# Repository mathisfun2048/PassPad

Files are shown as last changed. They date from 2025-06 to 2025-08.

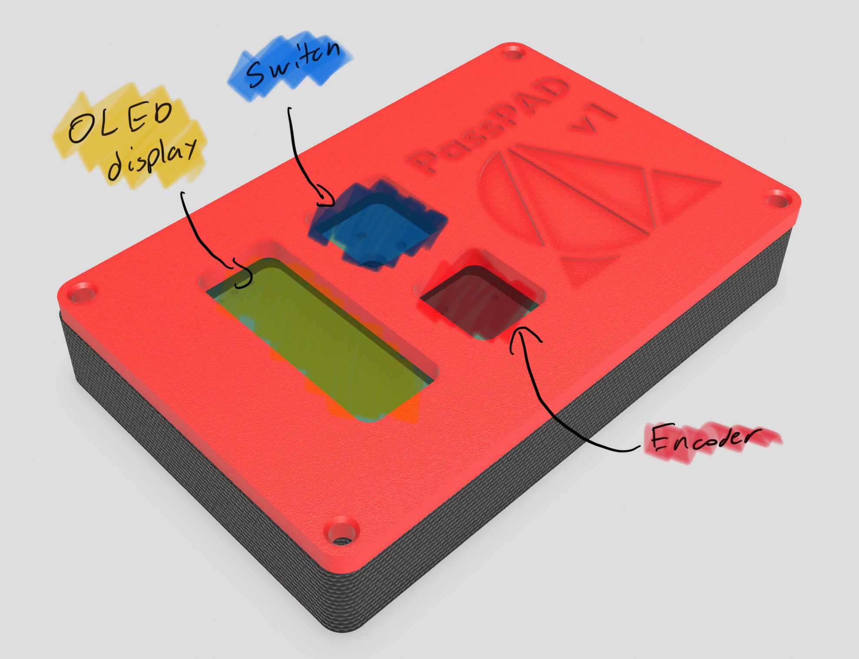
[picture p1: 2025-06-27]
Assests/CAD_Case_Together_Front.jpg

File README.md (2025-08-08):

# PassPAD 

Initial Sketch



## Description and Exigence

This is my fourth attempt at hardware design, and it's been so much fun!

One thing I've been dreading about starting college is moving away from my mac to use a windows laptop for my engineering degree. One of my key contentions was not being able to use the in-built password manger to hold large, secure passwords that I would have otherwise not been able to memorize. This project aims to help me in this problem. 

This device is going to hold passwords with a nickname. The encoder will be able to rotate between saved passwords, with the nickname appearing on the OLED dispaly. The password can be "typed" by repeatedly pressing the switch, which will dynamically change to the charachter next in the password. As a password is being typed, a completion bar will appear on the OLED> After the password is typed, a "completed" message will appear on the oled.

While the hardware for this is pretty simple, the software was not. Instead of being able to use the KMK or QMK frameworks, I learned circuitpython to make this hardware truly custom. I havn't seen a physical password transporter anywhere on the market, so it was really cool building this from scratch. (I submitted it as a 4-point project as my BOM ~$50 , but if you think it may warrent 6 points, please upgrade it :3 )

The design philosophy behind the CAD case for this is similar to my PaperCAM project: I wanted it to be sleek and minimal, in part not to draw attention. This, after all, contains my passwords! I do not want it to be flashy. That's why the case looks quite non-descrcipt. I wanted to add some custimizations, though, so I engraved my logo and a text that reads "PassPad v1". 

In line with keeping things simple (and affordable), I chose a very minimalistic BOM. Here it is below! It is also copied at the end of this README. 

NOTE: I know some items can be found cheaper through other retailars: the only problem is that my parents will only let me buy from the retailors below. If the cost goes above teh allocated cost for my project, I will hapilly pay out of my own pocket. I am grateful to have the opportunity to build this, and I cannot do so if I don't buy the parts from the retailors below.

|Item |Quantity|Cost |Link |
|---|---|-----|---|
|0.91 OLED Display  |1 |5.99 |https://www.amazon.com/gp/product/B08F9F8BYB/ref=ewc_pr_img_3?smid=A3CX4TQNUXMB0L&th=1 |
|EC11 Rotary Encoder|1 |0 |n/a I should have spares from the Hackpad kit |
|MX-Style Switch |1 |0 |n/a I should have spares from the Hackpad kit |
|White DSA Keycap |1 |0 |n/a I should have spares from the Hackpad kit|
                                                                                                                                            |
|XIAO Microprocessor|1       |9.99 |https://www.amazon.com/gp/product/B09NNVNW7M/ref=ox_sc_act_title_1?smid=A1YP59NGBNBZUR&psc=1                                                                                                                                                                                                                                                                                                                                                                                                                                                                 |
|Custom PCB         |1       |2  + shipping  |https://jlcpcb.com                                                                                                                                                                                                                                                                                                                                                                                                                                                                                                                                           |
|2.5M x 4mm Screws  |8       |0    |n/a, self-provided                                                                                                                                                                                                                                                                                                                                                                                                                                                                                                                                           |
|                   |        |~$38|                                                                                                                                                                                                                                                                                                                                                                                                                                                                                                                                                             |

## Schematic and PCB Design

For this project, I kept pretty much exactly to my initial sketch. Here's some images!

### Schematic
Screenshot 2025-07-02 at 4 01 11 AM

### PCB
Screenshot 2025-07-02 at 4 00 47 AM

## Firmware

Custom firmware! It was super fun to make. If you want a detailed view into my mindset, check out my journal! The runtime script is also included in this repo under the firmware and production directories. 

The code for this project was signficantly longer than teh code for my other projects (being ~600ish lines). I think that's a record for me! I experienced a lot of growth as a dev in this project as I was really able to exercise skills in error handeling and encryption. It was really satisfying to know that the code I have is for a project that I will use rather than something for a test. 

## CAD

The CAD case, like I said above, is simple by design: it is meant to be non-descript so people don't want to steal my passwords (litteraly). Here's some pretty renders of how everything looked at the end. Also, like the PaperCAM, as there is no wiring outside the PCB, no pretty sketch :(. However, I did annotate some of teh images below!

CAD_Case_Together_Front
CAD_Case_Together_Back
CAD_Case_Seperated_Front

## BOM

NOTE: I know some items can be found cheaper through other retailars: the only problem is that my parents will only let me buy from the retailors below. If the cost goes above teh allocated cost for my project, I will hapilly pay out of my own pocket. I am grateful to have the opportunity to build this, and I cannot do so if I don't buy the parts from the retailors below.

|Item |Quantity|Cost |Link |
|---|---|-----|---|
|0.91 OLED Display  |1 |5.99 |https://www.amazon.com/gp/product/B08F9F8BYB/ref=ewc_pr_img_3?smid=A3CX4TQNUXMB0L&th=1 |
|EC11 Rotary Encoder|1 |0 |n/a I should have spares from the Hackpad kit |
|MX-Style Switch |1 |0 |n/a I should have spares from the Hackpad kit |
|White DSA Keycap |1 |0 |n/a I should have spares from the Hackpad kit|
                                                                                                                                                                                                                                                                                                                                           |
|XIAO Microprocessor|1       |9.99 |https://www.amazon.com/gp/product/B09NNVNW7M/ref=ox_sc_act_title_1?smid=A1YP59NGBNBZUR&psc=1                                                                                                                                                                                                                                                                                                                                                                                                                                                                 |
|Custom PCB         |1       |2  + shipping  |https://jlcpcb.com                                                                                                                                                                                                                                                                                                                                                                                                                                                                                                                                           |
|2.5M x 4mm Screws  |8       |0    |n/a, self-provided                                                                                                                                                                                                                                                                                                                                                                                                                                                                                                                                           |
|                   |        |~$38|                                                                                                                                                                                                                                                                                                                                                                                                                                                                                                                                                             |

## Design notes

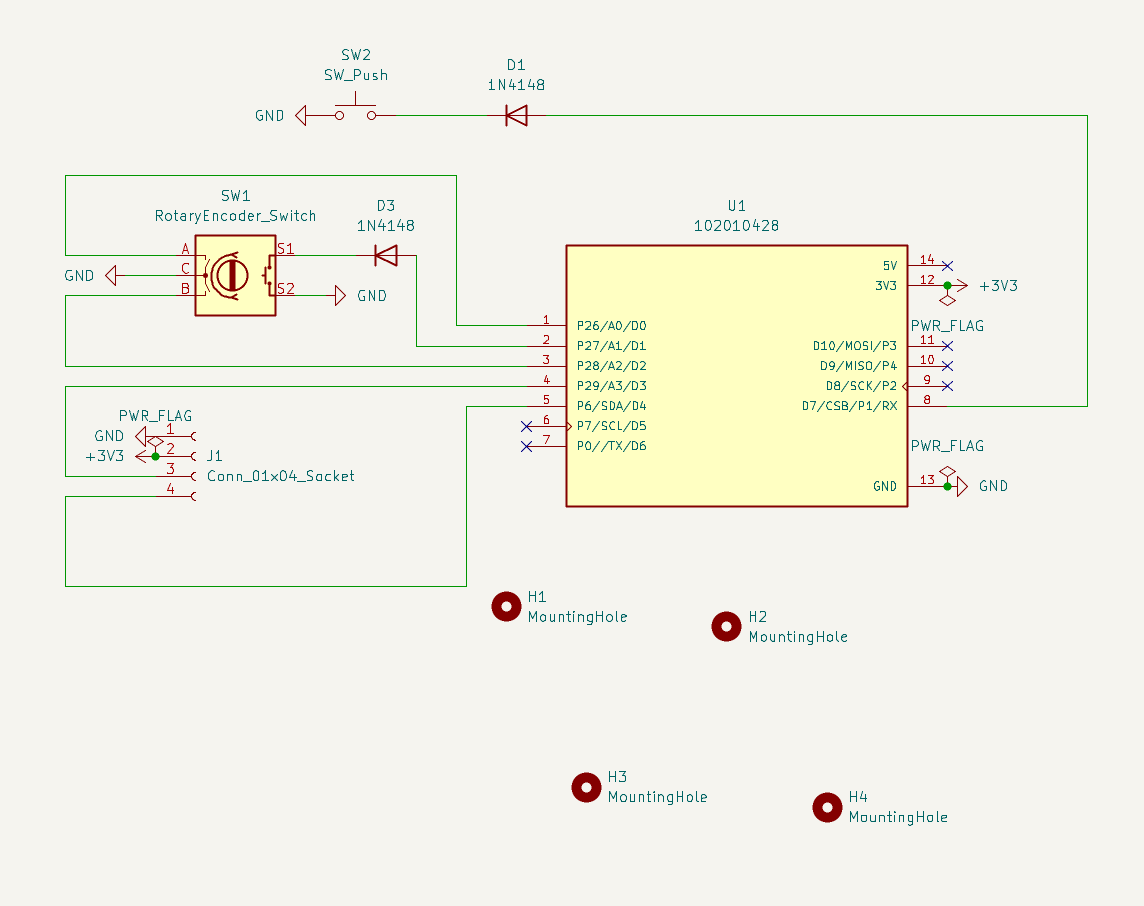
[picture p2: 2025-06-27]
Assests/Schematic.png

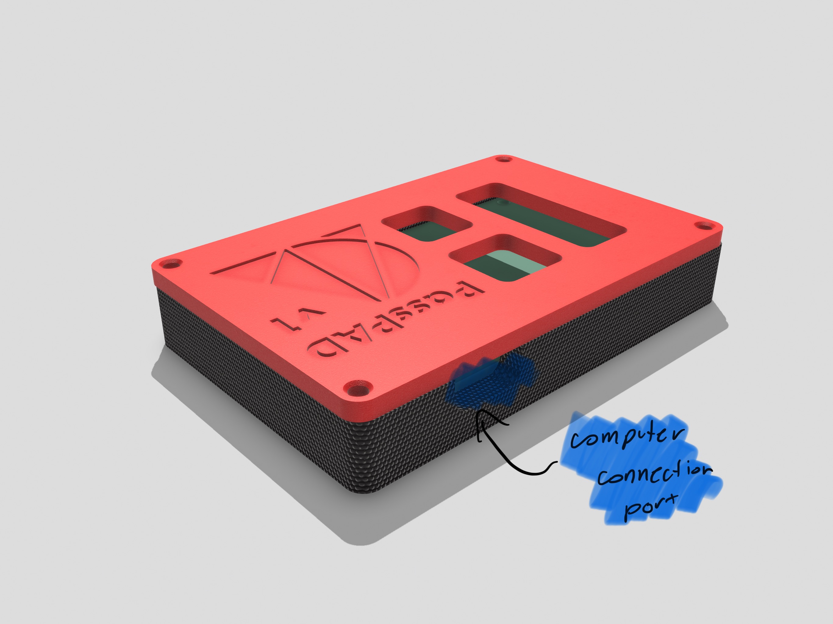
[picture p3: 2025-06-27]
Assests/CAD_Case_Together_Back.jpg

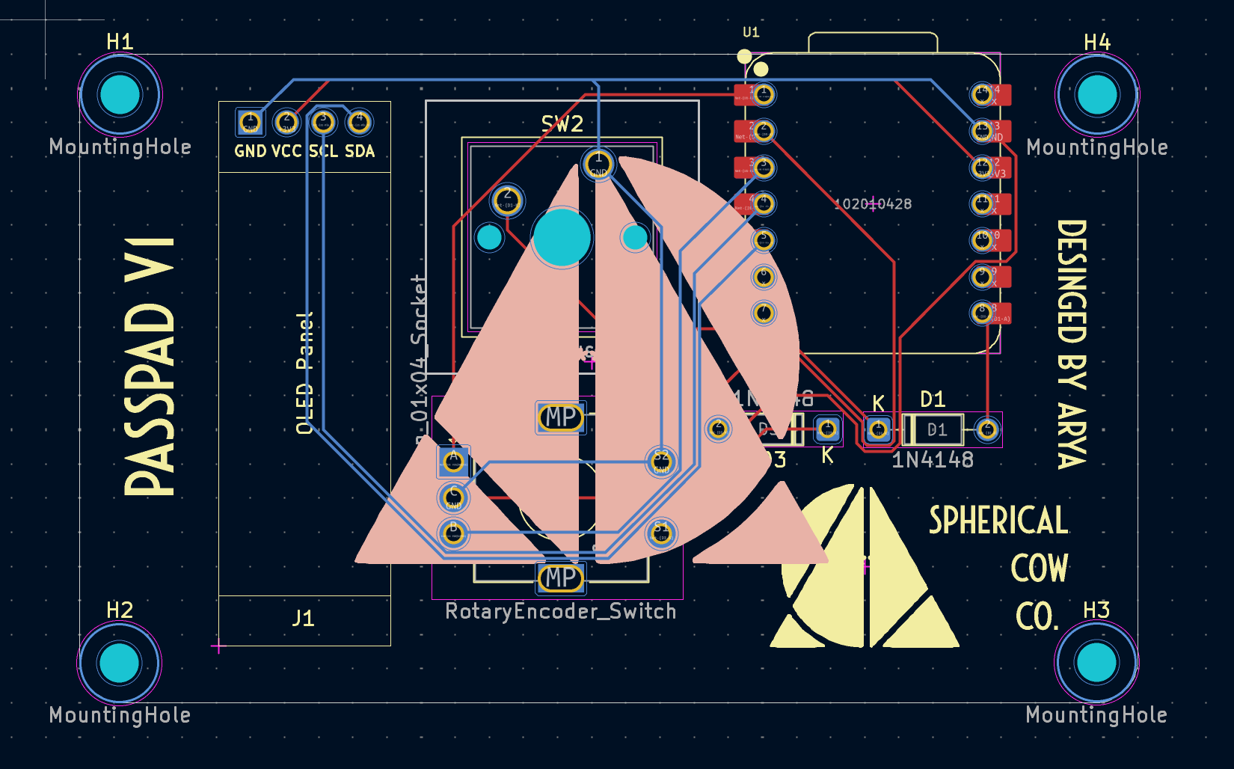
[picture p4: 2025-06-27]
Assests/PCB.png

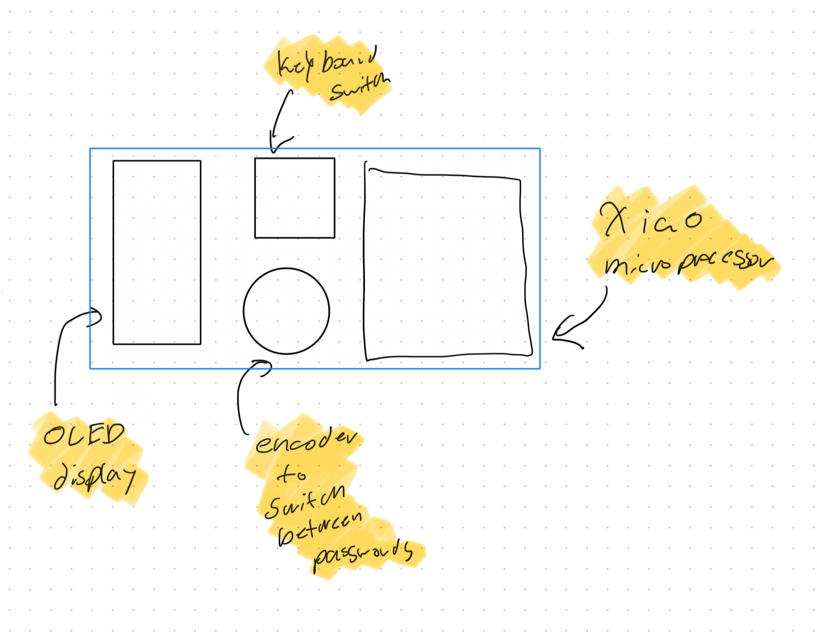
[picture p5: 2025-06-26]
Assests/Initial Sketch.jpg

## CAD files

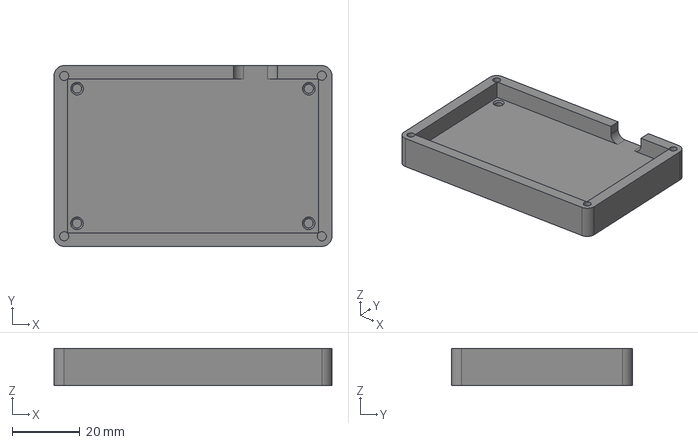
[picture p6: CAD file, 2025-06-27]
CAD/PassPAD_Case_Separates_STEP/Body 133.step
81.8 x 53.2 x 11.0 mm

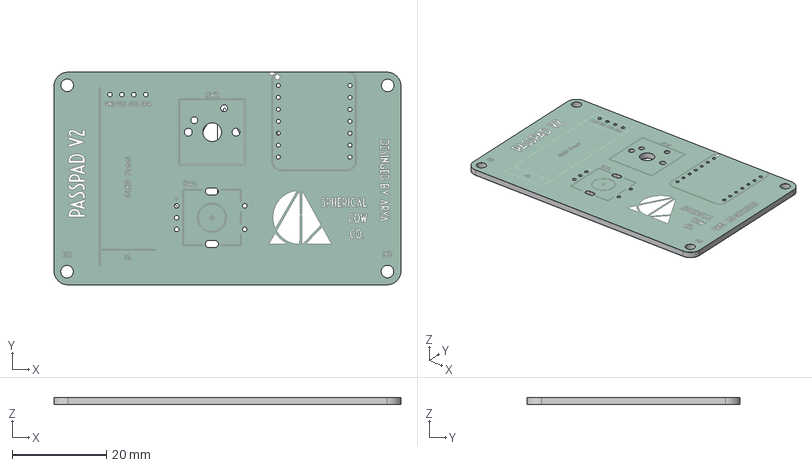
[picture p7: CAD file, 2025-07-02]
CAD/PassPad_PCB_STEP.step
73.8 x 45.2 x 1.66 mm
PassPad_KiCAD_silkscreen
PassPad_KiCAD_soldermask
PassPad_KiCAD_PCB

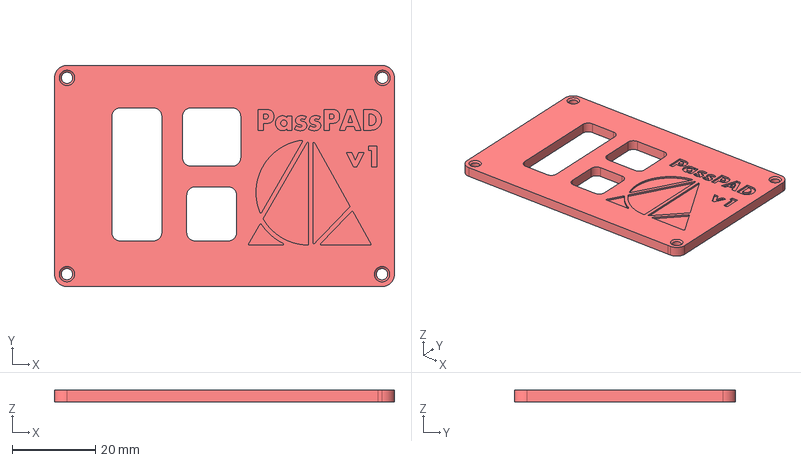
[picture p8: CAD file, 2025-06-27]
CAD/PassPAD_Case_Separates_STEP/Body 140.step
81.8 x 53.2 x 3.00 mm

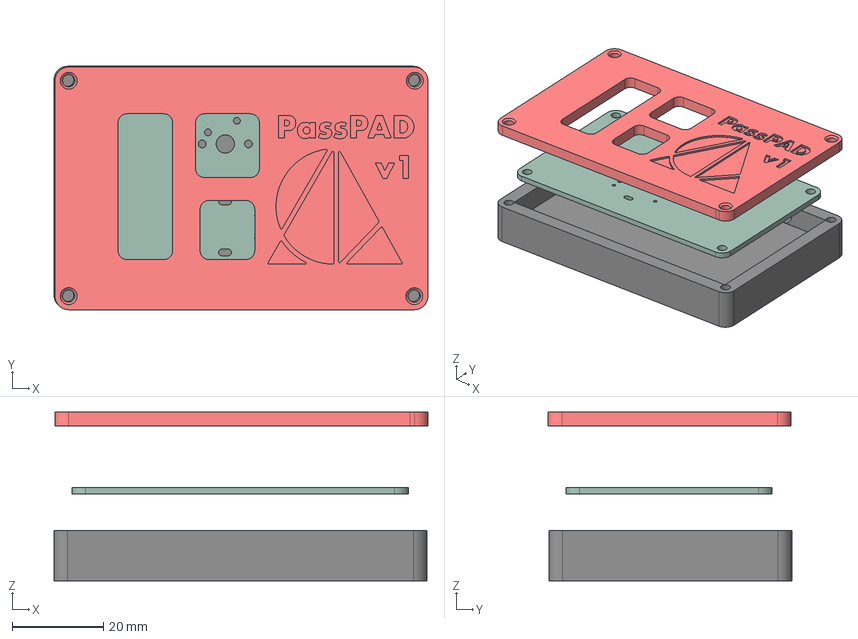
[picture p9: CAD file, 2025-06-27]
CAD/PassPAD_Together.step
82.0 x 53.4 x 37.0 mm
final logo doc svg
PassPad_KiCAD_PCB

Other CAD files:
Production/PassPAD_STL_Seperates/Body 133.stl
Production/PassPAD_STL_Seperates/Body 140.stl

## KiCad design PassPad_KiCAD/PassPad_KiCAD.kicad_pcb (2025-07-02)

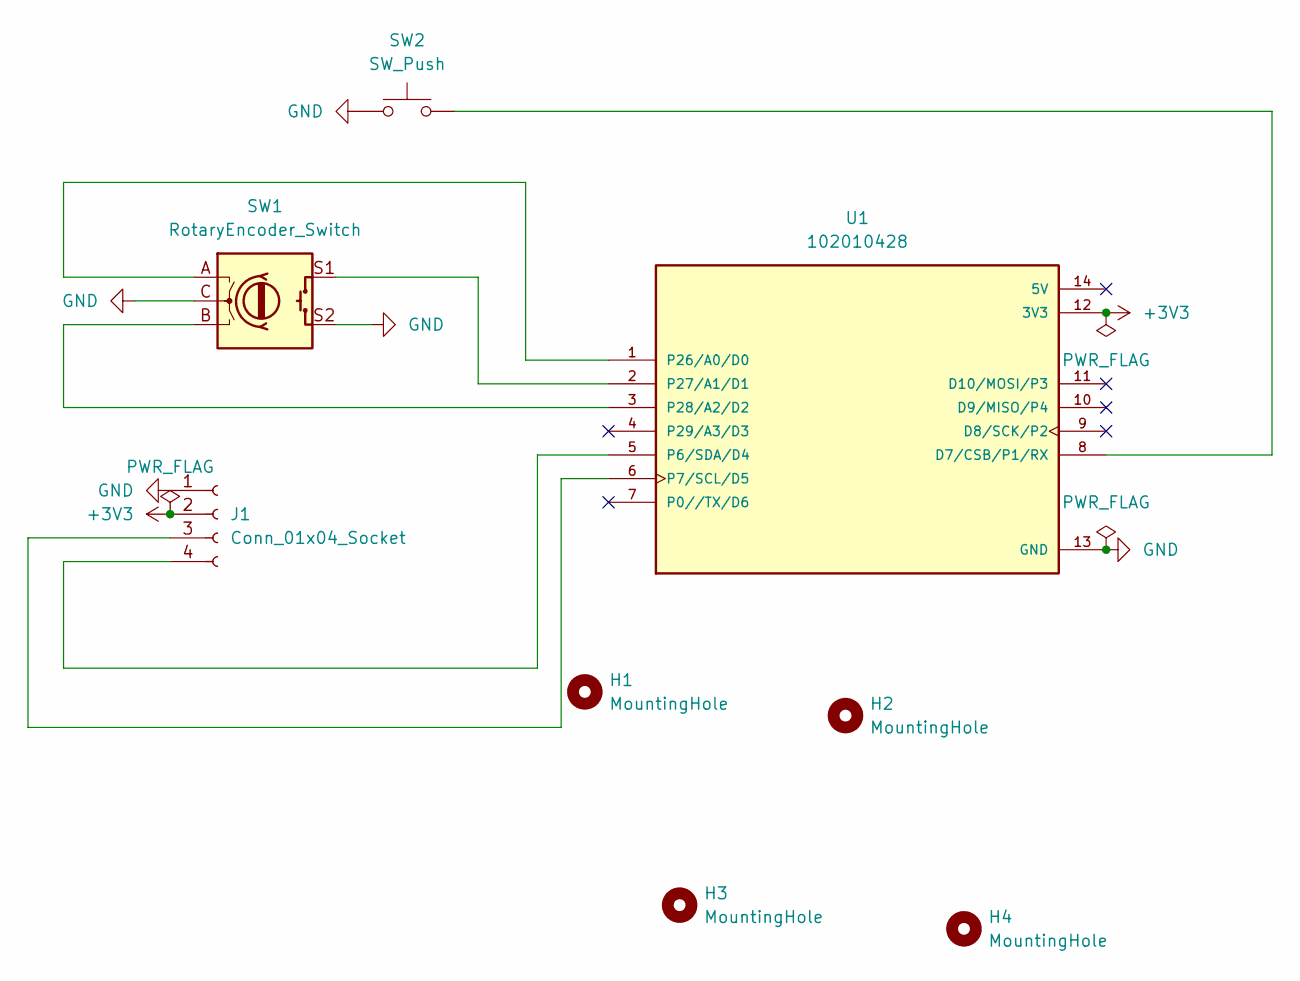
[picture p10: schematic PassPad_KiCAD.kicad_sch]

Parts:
H1, H2, H3, H4: MountingHole; MountingHole_2.7mm_M2.5
J1: Conn_01x04_Socket; SSD1306-0.91-OLED-4pin-128x32
SW1: RotaryEncoder_Switch; RotaryEncoder_Alps_EC11E-Switch_Vertical_H20mm
SW2: SW_Push; SW_Cherry_MX_1.00u_PCB
U1: 102010428; XIAO-through-hole; PARTREV 1.3; DigiKey_Part_Number 1597-102010428-ND

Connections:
+3V3: J1.2, U1.12 (3V3)
GND: J1.1, SW1.C, SW1.S2, SW2.1, U1.13 (GND)
unnamed: J1.3, U1.6 (P7/SCL/D5)
unnamed: J1.4, U1.5 (P6/SDA/D4)
unnamed: SW2.2, U1.8 (D7/CSB/P1/RX)
unnamed: SW1.A, U1.1 (P26/A0/D0)
unnamed: SW1.S1, U1.2 (P27/A1/D1)
unnamed: SW1.B, U1.3 (P28/A2/D2)

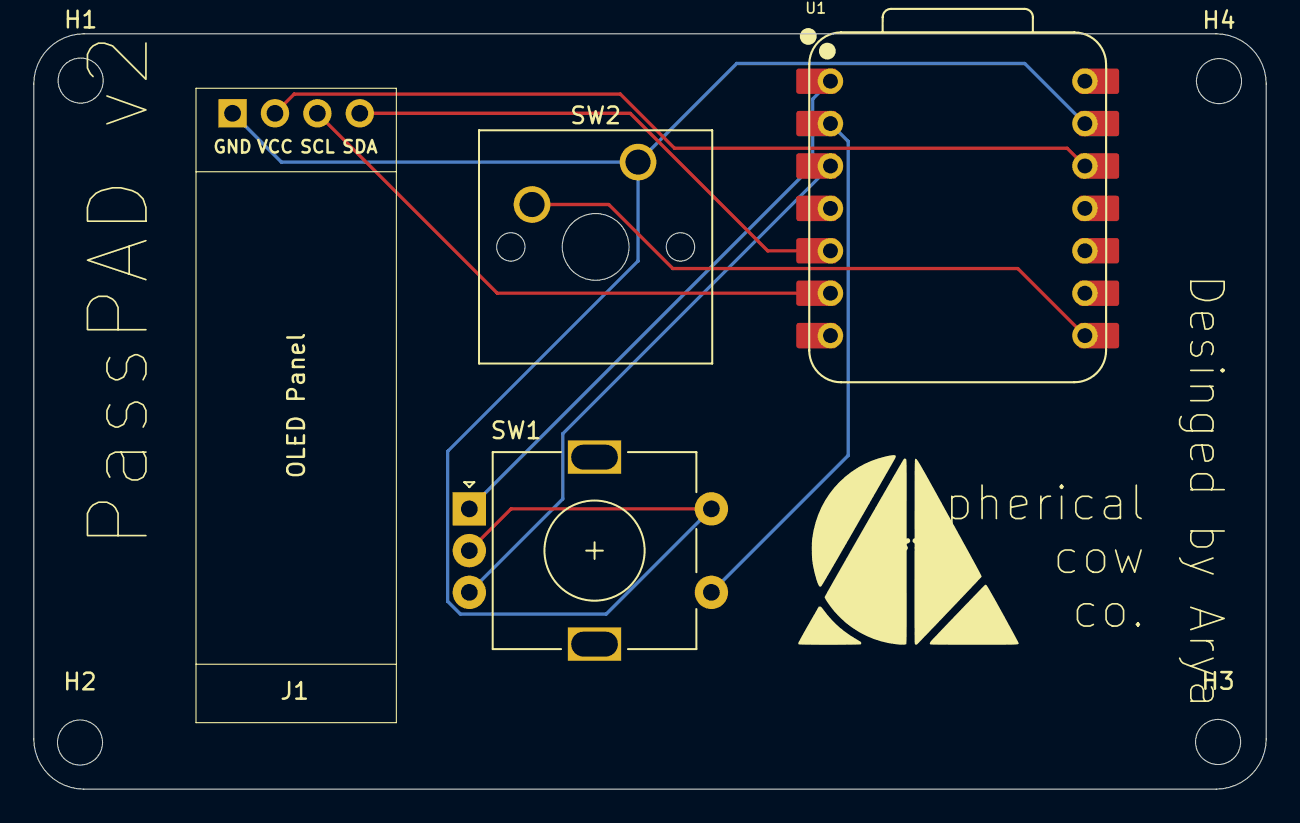
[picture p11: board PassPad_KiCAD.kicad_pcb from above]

Board: 2 copper layers, 73.8 x 45.2 mm, 8 parts (0 on the bottom side), 8 nets.

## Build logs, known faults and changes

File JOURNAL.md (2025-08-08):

---
title: "PassPad"
author: "Arya C."
description: "Convinent way to physically transport a password! (I love my password manager but what if I need to log into a public device where I don't want to link that?)"
created_at: "06-26-2025"
---

time spent (so far): 22 hours

# June 26

## 2PM -> 3PM (1 hour)

Spent this time researching possible parts and drawing a sketch of what I want this to look like. After, I wrote out the explicit objectives of this project. 

### Initial Sketch
Initial Sketch

### Interem BOM
- 0.91 OLED Display
- EC11 Rotary Encoder
- MX-Style Switch
- White DSA Keycap
- 1N4148 Diodes
- XIAO Microprocessor
- Custom PCB
- 3D Printed Case
- 2.5M x 4mm Screws

### Required Functionality
This project is meant to be a compact password transporter to where you need to have a secure password but don't want to log into your password manager. 

- This device should be able to store multiple passwords which the encoder should be able to rotate between
- The OLED pannel should display a short codename for the password (e.x. "password 1")
- The switch should then be repeatedly pressed until the password in its entierity is transmitted
- After the password is transmitted, no new data should be pushed even if the switch is pressed. The OLED pannel should communicate that the password has been transmitted (e.x. "successful")

sidenote: i've been going into a slump over desiging and itterating complex designs so I thought making this would be a fun in-between project. 

## 6PM -> 8PM (2 hours)

While making the schematic, went into a deep-dive on how microprocessors work! In the past, I only really worked with full on machines (raspberri pi zeros, 3b+) so seeing how this worked in a custom project was pretty cool. 

After looking into that, I started on my PCB schematic. This is, compared to my other projects, stupidly simple. But it was cool nonetheless--I have never seen a similar device in the wild and it feels really cool being able to build something. 

Schematic

### GPIO Guide
- 3.3v -> 3.3V (-> implicitly attached to VCC on display)
- GND -> GND (-> implicitly attached to GND on display, C pin on encoder, switch on encoder, and switch)
- Pin 1 -> diode -> one side of switch (other side is grounded)
- Pin 26 -> A pin on encoder
- Pin 27 -> diode -> one side of switch on encoder (other switch on encoder is grounded)
- Pin 28 -> B pin on encoder
- Pin 29 -> SCL on display
- Pin 6 -> SDA on display

now onto the PCB design!

## 8PM -> 9PM (1 hour)

Finished the PCB!

Screenshot 2025-06-27 at 2 07 22 AM

Now time for the beast: coding it. I remember last time I used micropython with this controler and it wasn't the worst... lets see how this goes. This project, in my opinion, is more complex algorithmically than the hackpad (which has a lot of open keyboard examples online which I could directly learn from). This is me operating it all on my own! I hope it'll be fun though...

# June 27

## 9PM -> 5AM 7AM -> 2PM (15 hours)

Finished my code! 

Who could have thought this would be so complicated! 

Okay so here was my process:
At first I started with micropython, becasue I thought it would be a similar proccess as to my hackpad. I was wrong....

Because my device is not purely a keybaord, I could not use KMK libraries... fun fun

So I went searching for soemthing that would be a tad bit more usable per my skill level, and I discovered circuit python! Which had a LOT of libraries I could use to not work in low-level code! YAY!

Here is everything I was able to import to help with the code:

Screenshot 2025-06-27 at 1 36 20 PM

One thing that I saw that made my code more rohbust was me being able to incorporate error handeling! I first truly learned the neccesity of it while making my PaperCAM project, and it was nice being able to see my learning and apply it to this. Error handeling is present primarily if the host device does not support HID, in which case the OLED pannel will display an error message. 

I wanted to incorporate a "copy" mode but then was lazy and forgot to do it. However, I was able to implement OS detection, so it will be reletivily easy to implmement that in the future. The reason I need OS detection is because I use a Mac which does not interpret CTRL+C as CMD+C. 

Overall, this was pretty fun, and you can see the full code in main.py under the firmware folder. 

I don't know really what else to add here, because my code is just a representation of my desgin statements that I made earlier in this journal. 

Now, onto the CAD!

## 2PM -> 4PM (2 Hours)

Finished the CAD case!

CAD_Case_Together_Front
CAD_Case_Together_Back
CAD_Case_Seperated_Front

## 4PM -> 5PM (1 Hour)

Put the repo all together for submission!

# July 2 

## 2AM -> 4AM (2 hours)

Was about to send this to print, but found some things I could revise. First, the dispaly wasn't wired propelry. I also found out that the display on my hackpad wasn't wired properly! I will have to change teh I2C on that manually through software. For this, though, I was able to fix it. I also removed teh diodes as they had no real purpous. I also cleaned up the PCB wiring. 

Screenshot 2025-07-02 at 3 58 58 AM

Screenshot 2025-07-02 at 3 59 11 AM

# I belive I have everything prepped for this project, including a Custom PCB, Custom Firmware, Custom Case, and associated components. The next step for me is to order my components and build this thing! Very excited

# One quick (and big) thank you to hack club for motivating me to do this project. Its ben an amazing run--thank you!

# August 4th 6PM -> 10PM (4 hours)

finally got around to making this!



was fairly easy, because I was able to re-use a lot of elements from my macropad. the soldering also went by well... im glad I'm getting better! I don't knwo what else to add here, because everything went smoothly, including the software, which is surprising. 

here is a demo video: https://youtube.com/shorts/AUEiD2HvVok

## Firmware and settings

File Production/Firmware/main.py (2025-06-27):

import time
import board
import busio
import digitalio
import rotaryio
import displayio
import terminalio
from adafruit_display_text import label
import adafruit_displayio_ssd1306
import usb_hid
from adafruit_hid.keyboard import Keyboard
from adafruit_hid.keycode import Keycode
import supervisor
import gc

CONFIG = {
    "os_type": "windows",
    "typing_delay": 0.02,
    "auto_lock_timeout": 300,
    "screen_brightness": 1.0,
}

DEVICE_KEY = 0xA5

def obfuscate_password(password):
    return ''.join(chr(ord(c) ^ DEVICE_KEY) for c in password)

def deobfuscate_password(obfuscated):
    return ''.join(chr(ord(c) ^ DEVICE_KEY) for c in obfuscated)

PASSWORDS = [
    {"name": "Password_1", "password": obfuscate_password("1234!")},
    {"name": "Password_2", "password": obfuscate_password("password")},
    {"name": "Password_3", "password": obfuscate_password("very-secure")},
    {"name": "Password_4", "password": obfuscate_password("passwordpassword")},
    {"name": "Password_5", "password": obfuscate_password("drowssap")},
]

class PasswordManagerError(Exception):
    pass

class PasswordManager:
    def __init__(self):
        self.error_count = 0
        self.max_errors = 5
        self.error_state = False
        self.last_error = None
        self.config_mode = False
        self.locked = False
        self.last_activity = time.monotonic()

        try:
            self.initialize_system()
        except Exception as e:
            self.handle_critical_error(f"Initialization failed: {e}")
            raise

    def initialize_system(self):
        print("Initializing Password Manager...")

        self.initialize_display()

        self.setup_hardware()

        self.initialize_hid()

        self.initialize_state()

        self.update_display()
        print("Password Manager initialization complete")

    def initialize_display(self):
        max_retries = 3
        for attempt in range(max_retries):
            try:
                displayio.release_displays()
                time.sleep(0.1)

                i2c = busio.I2C(board.P29, board.P6)
                display_bus = displayio.I2CDisplay(i2c, device_address=0x3C)
                self.display = adafruit_displayio_ssd1306.SSD1306(display_bus, width=128, height=32)

                self.splash = displayio.Group()
                self.display.show(self.splash)
                return

            except Exception as e:
                print(f"Display init attempt {attempt+1} failed: {e}")
                if attempt == max_retries - 1:
                    raise PasswordManagerError(f"Display initialization failed after {max_retries} attempts")
                time.sleep(0.5)

    def setup_hardware(self):
        try:
            self.switch = digitalio.DigitalInOut(board.P1)
            self.switch.direction = digitalio.Direction.INPUT
            self.switch.pull = digitalio.Pull.DOWN

            try:
                self.encoder = rotaryio.IncrementalEncoder(board.P26, board.P28)
                self.encoder_available = True
            except Exception as e:
                print(f"Encoder initialization failed: {e}")
                self.encoder = None
                self.encoder_available = False

            self.encoder_switch = digitalio.DigitalInOut(board.P27)
            self.encoder_switch.direction = digitalio.Direction.INPUT
            self.encoder_switch.pull = digitalio.Pull.DOWN

        except Exception as e:
            raise PasswordManagerError(f"Hardware setup failed: {e}")

    def initialize_hid(self):
        self.keyboard = None
        self.hid_available = False

        try:
            if not usb_hid.devices:
                print("Warning: No USB HID devices found")
                return

            self.keyboard = Keyboard(usb_hid.devices)
            self.hid_available = True

        except Exception as e:
            print(f"USB HID initialization failed: {e}")
            self.keyboard = None
            self.hid_available = False

    def initialize_state(self):
        self.current_password_index = 0
        self.current_char_index = 0
        self.password_transmitted = False
        self.last_encoder_position = self.encoder.position if self.encoder_available else 0

        self.config_option = 0
        self.config_options = ["OS Type", "Typing Delay", "Auto Lock"]

        self.last_switch_time = 0
        self.debounce_delay = 0.3

    def update_activity(self):
        self.last_activity = time.monotonic()

    def check_auto_lock(self):
        if CONFIG["auto_lock_timeout"] > 0 and not self.locked:
            if time.monotonic() - self.last_activity > CONFIG["auto_lock_timeout"]:
                self.locked = True
                self.safe_display_update(self.update_display)

    def unlock_device(self):
        self.locked = False
        self.update_activity()
        self.safe_display_update(self.update_display)

    def secure_clear_password(self, password_data):
        try:
            if isinstance(password_data, str):
                password_data = "0" * len(password_data)
            gc.collect()
        except:
            pass

    def handle_error(self, error_msg):
        self.error_count += 1
        self.last_error = error_msg
        print(f"Error {self.error_count}: {error_msg}")

        if self.error_count >= self.max_errors:
            self.error_state = True
            self.show_error_screen("Too many errors", "Device in safe mode")
            return False

        if "display" in error_msg.lower():
            self.recover_display()
        elif "hid" in error_msg.lower():
            self.recover_hid()
        elif "encoder" in error_msg.lower():
            self.recover_encoder()

        return True

    def handle_critical_error(self, error_msg):
        print(f"CRITICAL ERROR: {error_msg}")
        try:
            if self.display:
                self.show_error_screen("CRITICAL ERROR", "Restarting...")
                time.sleep(3)
        except:
            pass
        supervisor.reload()

    def recover_display(self):
        try:
            self.initialize_display()
            self.update_display()
            return True
        except Exception as e:
            print(f"Display recovery failed: {e}")
            return False

    def recover_hid(self):
        try:
            time.sleep(1)
            self.initialize_hid()
            return self.hid_available
        except Exception as e:
            print(f"HID recovery failed: {e}")
            return False

    def recover_encoder(self):
        try:
            self.encoder = rotaryio.IncrementalEncoder(board.P26, board.P28)
            self.encoder_available = True
            self.last_encoder_position = self.encoder.position
            return True
        except Exception as e:
            print(f"Encoder recovery failed: {e}")
            self.encoder_available = False
            return False

    def show_error_screen(self, title, message):
        try:
            if not self.display:
                return

            self.display.show(None)
            group = displayio.Group()

            text1 = label.Label(terminalio.FONT, text=title, color=0xFFFFFF, x=5, y=8)
            text2 = label.Label(terminalio.FONT, text=message, color=0xFFFFFF, x=5, y=18)
            text3 = label.Label(terminalio.FONT, text="Press encoder to retry", color=0xFFFFFF, x=2, y=28)

            group.append(text1)
            group.append(text2)
            group.append(text3)

            self.display.show(group)
        except Exception as e:
            print(f"Error displaying error screen: {e}")

    def safe_display_update(self, update_func):
        try:
            update_func()
        except Exception as e:
            if not self.handle_error(f"Display update failed: {e}"):
                return False
        return True

    def update_display(self):
        try:
            if self.display:
                self.display.show(None)

            gc.collect()
            self.splash = displayio.Group()

            if self.locked:
                text1 = label.Label(terminalio.FONT, text="DEVICE LOCKED", color=0xFFFFFF, x=15, y=8)
                text2 = label.Label(terminalio.FONT, text="Press encoder", color=0xFFFFFF, x=18, y=18)
                text3 = label.Label(terminalio.FONT, text="to unlock", color=0xFFFFFF, x=25, y=28)
                self.splash.append(text1)
                self.splash.append(text2)
                self.splash.append(text3)

            elif self.config_mode:
                self.display_config_screen()

            elif self.error_state:
                text1 = label.Label(terminalio.FONT, text="SAFE MODE", color=0xFFFFFF, x=25, y=8)
                text2 = label.Label(terminalio.FONT, text="Multiple errors", color=0xFFFFFF, x=8, y=18)
                text3 = label.Label(terminalio.FONT, text="Hold encoder: reset", color=0xFFFFFF, x=2, y=28)
                self.splash.append(text1)
                self.splash.append(text2)
                self.splash.append(text3)

            elif not self.hid_available:
                text1 = label.Label(terminalio.FONT, text="USB HID ERROR", color=0xFFFFFF, x=15, y=8)
                text2 = label.Label(terminalio.FONT, text="Check USB connection", color=0xFFFFFF, x=5, y=18)
                self.splash.append(text1)
                self.splash.append(text2)

            elif self.password_transmitted:
                text1 = label.Label(terminalio.FONT, text="SUCCESS!", color=0xFFFFFF, x=30, y=8)
                text2 = label.Label(terminalio.FONT, text="Password sent", color=0xFFFFFF, x=15, y=18)
                text3 = label.Label(terminalio.FONT, text="Press encoder: reset", color=0xFFFFFF, x=2, y=28)
                self.splash.append(text1)
                self.splash.append(text2)
                self.splash.append(text3)
            else:
                password_info = PASSWORDS[self.current_password_index]

                name = password_info["name"]
                if len(name) > 18:
                    name = name[:15] + "..."
                text1 = label.Label(terminalio.FONT, text=name, color=0xFFFFFF, x=5, y=8)

                actual_password = deobfuscate_password(password_info["password"])

                progress = f"{self.current_char_index}/{len(actual_password)}"
                os_status = f"OS: {CONFIG['os_type']}"
                text2 = label.Label(terminalio.FONT, text=f"{progress}  {os_status}", color=0xFFFFFF, x=5, y=18)

                text3 = label.Label(terminalio.FONT, text="Switch+Enc: config", color=0xFFFFFF, x=5, y=28)

                self.splash.append(text1)
                self.splash.append(text2)
                self.splash.append(text3)

                self.secure_clear_password(actual_password)

            if self.display:
                self.display.show(self.splash)

        except Exception as e:
            print(f"Display update error: {e}")
            self.handle_error(f"Display update failed: {e}")

    def display_config_screen(self):
        global value, value
        option_name = self.config_options[self.config_option]

        if self.config_option == 0:
            value = CONFIG["os_type"]
        elif self.config_option == 1:
            value = f"{CONFIG['typing_delay']:.3f}s"
        elif self.config_option == 2:
            value = f"{CONFIG['auto_lock_timeout']}s" if CONFIG['auto_lock_timeout'] > 0 else "OFF"

        text1 = label.Label(terminalio.FONT, text="CONFIG MODE", color=0xFFFFFF, x=20, y=8)
        text2 = label.Label(terminalio.FONT, text=f"{option_name}: {value}", color=0xFFFFFF, x=5, y=18)
        text3 = label.Label(terminalio.FONT, text="Rotate: change, Press: next", color=0xFFFFFF, x=2, y=28)

        self.splash.append(text1)
        self.splash.append(text2)
        self.splash.append(text3)

    def handle_encoder(self):
        if self.locked or self.error_state or not self.encoder_available:
            return

        try:
            current_position = self.encoder.position
            if current_position != self.last_encoder_position:
                difference = current_position - self.last_encoder_position
                self.update_activity()

                if self.config_mode:
                    self.handle_config_rotation(difference)
                else:
                    if difference > 0:
                        self.current_password_index = (self.current_password_index + 1) % len(PASSWORDS)
                    else:
                        self.current_password_index = (self.current_password_index - 1) % len(PASSWORDS)

                    self.reset_transmission()

                self.last_encoder_position = current_position
                self.safe_display_update(self.update_display)
                time.sleep(0.1)

        except Exception as e:
            print(f"Encoder handling error: {e}")
            if not self.handle_error(f"Encoder error: {e}"):
                self.encoder_available = False

    def handle_config_rotation(self, difference):
        if self.config_option == 0:
            os_types = ["windows", "macos", "linux"]
            current_index = os_types.index(CONFIG["os_type"])
            if difference > 0:
                current_index = (current_index + 1) % len(os_types)
            else:
                current_index = (current_index - 1) % len(os_types)
            CONFIG["os_type"] = os_types[current_index]

        elif self.config_option == 1:
            if difference > 0:
                CONFIG["typing_delay"] = min(0.2, CONFIG["typing_delay"] + 0.01)
            else:
                CONFIG["typing_delay"] = max(0.0, CONFIG["typing_delay"] - 0.01)

        elif self.config_option == 2:
            if difference > 0:
                if CONFIG["auto_lock_timeout"] == 0:
                    CONFIG["auto_lock_timeout"] = 60
                else:
                    CONFIG["auto_lock_timeout"] = min(1800, CONFIG["auto_lock_timeout"] + 60)
            else:
                if CONFIG["auto_lock_timeout"] <= 60:
                    CONFIG["auto_lock_timeout"] = 0
                else:
                    CONFIG["auto_lock_timeout"] = max(0, CONFIG["auto_lock_timeout"] - 60)

    def get_key_mapping(self):
        mapping = {
            '!': (Keycode.SHIFT, Keycode.ONE),
            '@': (Keycode.SHIFT, Keycode.TWO),
            '#': (Keycode.SHIFT, Keycode.THREE),
            '$': (Keycode.SHIFT, Keycode.FOUR),
            '%': (Keycode.SHIFT, Keycode.FIVE),
            '^': (Keycode.SHIFT, Keycode.SIX),
            '&': (Keycode.SHIFT, Keycode.SEVEN),
            '*': (Keycode.SHIFT, Keycode.EIGHT),
            '(': (Keycode.SHIFT, Keycode.NINE),
            ')': (Keycode.SHIFT, Keycode.ZERO),
            '_': (Keycode.SHIFT, Keycode.MINUS),
            '+': (Keycode.SHIFT, Keycode.EQUALS),
            ':': (Keycode.SHIFT, Keycode.SEMICOLON),
            '"': (Keycode.SHIFT, Keycode.QUOTE),
            '<': (Keycode.SHIFT, Keycode.COMMA),
            '>': (Keycode.SHIFT, Keycode.PERIOD),
            '?': (Keycode.SHIFT, Keycode.FORWARD_SLASH),
            '-': (Keycode.MINUS,),
            '=': (Keycode.EQUALS,),
            ';': (Keycode.SEMICOLON,),
            "'": (Keycode.QUOTE,),
            ',': (Keycode.COMMA,),
            '.': (Keycode.PERIOD,),
            '/': (Keycode.FORWARD_SLASH,),
            ' ': (Keycode.SPACE,),
        }

        if CONFIG["os_type"] == "macos":
            mapping['['] = (Keycode.LEFT_BRACKET,)
            mapping[']'] = (Keycode.RIGHT_BRACKET,)
            mapping['\\'] = (Keycode.BACKSLASH,)
            mapping['~'] = (Keycode.SHIFT, Keycode.GRAVE_ACCENT)
            mapping['`'] = (Keycode.GRAVE_ACCENT,)
        else:
            mapping['['] = (Keycode.LEFT_BRACKET,)
            mapping[']'] = (Keycode.RIGHT_BRACKET,)
            mapping['\\'] = (Keycode.BACKSLASH,)
            mapping['~'] = (Keycode.SHIFT, Keycode.GRAVE_ACCENT)
            mapping['`'] = (Keycode.GRAVE_ACCENT,)

        return mapping

    def send_next_character(self):
        if not self.hid_available or self.error_state or self.locked:
            return

        obfuscated_password = PASSWORDS[self.current_password_index]["password"]
        password = deobfuscate_password(obfuscated_password)

        if self.current_char_index >= len(password):
            self.secure_clear_password(password)
            return

        char = password[self.current_char_index]
        key_mapping = self.get_key_mapping()

        try:
            if char in key_mapping:
                self.keyboard.send(*key_mapping[char])
            elif char.isalpha():
                if char.isupper():
                    self.keyboard.send(Keycode.SHIFT, getattr(Keycode, char))
                else:
                    self.keyboard.send(getattr(Keycode, char.upper()))
            elif char.isdigit():
                digit_map = {
                    '0': Keycode.ZERO, '1': Keycode.ONE, '2': Keycode.TWO,
                    '3': Keycode.THREE, '4': Keycode.FOUR, '5': Keycode.FIVE,
                    '6': Keycode.SIX, '7': Keycode.SEVEN, '8': Keycode.EIGHT,
                    '9': Keycode.NINE
                }
                self.keyboard.send(digit_map[char])
            else:
                print(f"Unhandled character: {char}")

            self.current_char_index += 1

            if CONFIG["typing_delay"] > 0:
                time.sleep(CONFIG["typing_delay"])

            if self.current_char_index >= len(password):
                self.password_transmitted = True

            self.secure_clear_password(password)

        except Exception as e:
            self.secure_clear_password(password)
            self.handle_error(f"Failed to send character: {e}")

    def reset_transmission(self):
        self.current_char_index = 0
        self.password_transmitted = False

    def factory_reset(self):
        try:
            self.error_state = False
            self.error_count = 0
            self.last_error = None
            self.config_mode = False
            self.locked = False
            self.reset_transmission()
            self.update_activity()

            CONFIG["os_type"] = "windows"
            CONFIG["typing_delay"] = 0.02
            CONFIG["auto_lock_timeout"] = 300

            self.initialize_hid()
            if not self.encoder_available:
                self.recover_encoder()

            self.safe_display_update(self.update_display)

        except Exception as e:
            self.handle_critical_error("Factory reset failed")

    def run(self):
        print("Password Manager Started")
        print(f"Loaded {len(PASSWORDS)} passwords")
        print(f"HID Available: {self.hid_available}")
        print(f"Encoder Available: {self.encoder_available}")

        consecutive_errors = 0
        max_consecutive_errors = 10
        encoder_press_start = None
        long_press_duration = 1.5
        config_combo_start = None
        config_combo_duration = 2.0

        while True:
            try:
                self.check_auto_lock()

                self.handle_encoder()

                if self.switch.value and not self.password_transmitted and not self.config_mode and not self.locked:
                    current_time = time.monotonic()
                    if current_time - self.last_switch_time > self.debounce_delay:
                        self.send_next_character()
                        self.last_switch_time = current_time
                        self.safe_display_update(self.update_display)
                        self.update_activity()

                if self.encoder_switch.value:
                    if encoder_press_start is None:
                        encoder_press_start = time.monotonic()
                    else:
                        press_duration = time.monotonic() - encoder_press_start

                        if press_duration >= long_press_duration and not self.locked:
                            self.factory_reset()
                            encoder_press_start = None

                        elif self.switch.value and press_duration >= config_combo_duration and not self.locked:
                            self.config_mode = not self.config_mode
                            self.safe_display_update(self.update_display)
                            encoder_press_start = None
                else:
                    if encoder_press_start is not None:
                        press_duration = time.monotonic() - encoder_press_start

                        if press_duration < long_press_duration:
                            if self.locked:
                                self.unlock_device()
                            elif self.config_mode:
                                self.config_option = (self.config_option + 1) % len(self.config_options)
                                self.safe_display_update(self.update_display)
                            else:
                                self.reset_transmission()
                                self.safe_display_update(self.update_display)

                        encoder_press_start = None
                        self.update_activity()

                    config_combo_start = None

                consecutive_errors = 0
                time.sleep(0.01)

            except Exception as e:
                consecutive_errors += 1
                print(f"Runtime error {consecutive_errors}: {e}")

                if consecutive_errors >= max_consecutive_errors:
                    self.handle_critical_error(f"Too many consecutive errors")
                    break

                time.sleep(0.1)
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

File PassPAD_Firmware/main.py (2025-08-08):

import board
import digitalio
import displayio
import adafruit_displayio_ssd1306
import terminalio
from adafruit_display_text import label
import time
import i2cdisplaybus

displayio.release_displays()

i2c = board.I2C()
display_bus = i2cdisplaybus.I2CDisplayBus(i2c, device_address=0x3C)
display = adafruit_displayio_ssd1306.SSD1306(display_bus, width=128, height=32)

switch = digitalio.DigitalInOut(board.D7)
switch.direction = digitalio.Direction.INPUT
switch.pull = digitalio.Pull.UP

enc_a = digitalio.DigitalInOut(board.D0)
enc_a.direction = digitalio.Direction.INPUT
enc_a.pull = digitalio.Pull.UP

enc_b = digitalio.DigitalInOut(board.D2)
enc_b.direction = digitalio.Direction.INPUT
enc_b.pull = digitalio.Pull.UP

codes = {
    "gmail": "ABC123XYZ",
    "discord": "DEF456UVW", 
    "reddit": "GHI789RST",
    "jetbrains": "JKL012MNO"
}

keys = list(codes.keys())
current_index = 0
last_enc_a_state = enc_a.value
switch_pressed = False
display_needs_update = True

splash = displayio.Group()
display.root_group = splash

text_area = label.Label(terminalio.FONT, text="", color=0xFFFFFF, x=64, y=16)
text_area.anchor_point = (0.5, 0.5)
text_area.anchored_position = (64, 16)
splash.append(text_area)

def update_display():
    global display_needs_update
    if not switch_pressed:
        text_area.text = keys[current_index]
    else:
        text_area.text = codes[keys[current_index]]
    display_needs_update = False

def check_rotary_encoder():
    global current_index, last_enc_a_state, display_needs_update
    
    current_a_state = enc_a.value
    
    if last_enc_a_state and not current_a_state:
        if enc_b.value:
            current_index = (current_index + 1) % len(keys)
        else:
            current_index = (current_index - 1) % len(keys)
        display_needs_update = True
    
    last_enc_a_state = current_a_state

while True:
    if display_needs_update:
        update_display()
    
    check_rotary_encoder()
    
    if not switch.value and not switch_pressed:
        switch_pressed = True
        display_needs_update = True
    
    if switch.value and switch_pressed:
        switch_pressed = False
        display_needs_update = True

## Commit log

2025-06-27 some files
    [PassPad_KiCAD.kicad_pcb, PassPad_KiCAD.kicad_sch]
2025-06-27 added some files
    [BOM for PassPAD - Sheet1.csv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]
2025-06-28 Update BOM for PassPAD - Sheet1.csv
    [BOM for PassPAD - Sheet1.csv]
2025-07-02 fixed PCB mistakes
    [PassPad_KiCAD-B_Cu.gbr, PassPad_KiCAD-B_Mask.gbr, PassPad_KiCAD-B_Paste.gbr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]
